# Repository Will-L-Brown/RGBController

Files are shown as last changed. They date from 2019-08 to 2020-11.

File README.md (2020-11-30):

# RGBController
Controller for RGB Strips and RGB Fans

Based on an Arduino Pro Micro (cheap chinese clone) 

Uses the FastLED library

Pin assignments can be found in the code

Recommended to have a resistor on the data output pins to the LED strips and fans, between 220Ω and 470Ω. I use 330Ω.

# 10-channel RGB Controller Hardware

This board is a custom board designed for hooking up to 10 aRGB devices with individual control using an Arduino Pro Micro. 

The Board features 9 3-pin aRGB headers and 1 Corsair RGB header. Idea is to have up to 8 RGB fans that are each individually addressable but do not pass the line back to have a combined effect, 
while also having a chain of Corsair RGB products and an aRGB strip.

There is a 3-button header for up to 3 standard case buttons, such as the unused reset switch!

This board is in a standard 2.5 inch drive format with mounting holes for easy case mounting.

# Known Hardware issues

- Rev 0.1A 
	- Incorrect pinout on the Corsair header
	
- Rev 0.1B
	- Corsair header does not have the best routing on VCC and GND to local filter capacitors
		- SMD stencil is compatible with Rev 0.1A hardware
	- BOM P/N for aRGB headers is incorrect. Correct part should be a 2.54mm spaced, 0.6mm diameter, right angle "Swiss machine pin" header to be compatible with standard aRGB connectors
		- I don't know of a good part number or source for this part. Contact me if you have a part number, or submit a pull request
	- BOM P/N for Molex power connect is likely not optimal. 
	- Spacing for aRGB headers may not be optimal for certain devices and may have clearance issues when completely populated
	- 0.1uF caps C12-16, C27-31 should not be populated. These destroy the signal from the ATMega and were intended for 5V-GND, not Din-GND

# Future Hardware To-Do

- Rev 0.1C
	- Re-routing filter caps for the Corsair header for better performace
- Future Variants
	- Change one aRGB header to a second Corsair header
	- Variant with 3 aRGB, 2 Cosair on one side, temp probes and fan headers on the other

# Off-The-Shelf components and LED Type
This is meant to use a variety of standard PC components as well as cheap RGB strips to produce the RGB effect.

A small list of various verified parts and their LED type are listed below:

- Corsair HD1x0 fans
    - WS2812B-based custom RGB modules
	- HD120: 12 LEDS
- Corsair XD5 Pump and Res Combo
    - WS2812B-based custom RGB modules
	- 10 LEDS
- Corsair XG7 RTX 2080 GPU Block
	- WS2812B-based custom RGB modules
	- 16 LEDS

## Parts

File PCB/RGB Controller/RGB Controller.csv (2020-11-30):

Source: | H:\Projects\8-ch RGB Controller\PCB\RGB Controller\RGB Controller.sch
Date: | 11/16/2020 6:00:43 PM
Tool: | Eeschema (5.1.7)-1
Generator: | C:\Program Files\KiCad\bin\scripting\plugins/bom_csv_grouped_by_value.py
Component Count: | 58
Individual Components:
Item | Qty | Reference(s) | Value | LibPart | Footprint | Datasheet | Digi-Key_PN | Field4 | MPN
 |  | B1 | SPARKFUN_PRO_MICRO | SparkFun-Boards:SPARKFUN_PRO_MICRO | Boards:SPARKFUN_PRO_MICRO |  |  | XXX-00000 | Pro Micro
 |  | C1 | 10uF | Device:C_Small | Capacitor_SMD:C_0603_1608Metric_Pad1.08x0.95mm_HandSolder | ~ | 1276-1119-1-ND |  | CL10A106MQ8NNNC
 |  | C2 | 10uF | Device:C_Small | Capacitor_SMD:C_0603_1608Metric_Pad1.08x0.95mm_HandSolder | ~ | 1276-1119-1-ND |  | CL10A106MQ8NNNC
 |  | C3 | 10uF | Device:C_Small | Capacitor_SMD:C_0603_1608Metric_Pad1.08x0.95mm_HandSolder | ~ | 1276-1119-1-ND |  | CL10A106MQ8NNNC
 |  | C4 | 10uF | Device:C_Small | Capacitor_SMD:C_0603_1608Metric_Pad1.08x0.95mm_HandSolder | ~ | 1276-1119-1-ND |  | CL10A106MQ8NNNC
 |  | C5 | 10uF | Device:C_Small | Capacitor_SMD:C_0603_1608Metric_Pad1.08x0.95mm_HandSolder | ~ | 1276-1119-1-ND |  | CL10A106MQ8NNNC
 |  | C6 | 10uF | Device:C_Small | Capacitor_SMD:C_0603_1608Metric_Pad1.08x0.95mm_HandSolder | ~ | 1276-1119-1-ND |  | CL10A106MQ8NNNC
 |  | C7 | 100uF | Device:CP1_Small | Custom Footprints:UWR1A101MCL1GB | ~ | 493-14561-1-ND |  | UWR1A101MCL1GB
 |  | C8 | 100uF | Device:CP1_Small | Custom Footprints:UWR1A101MCL1GB | ~ | 493-14561-1-ND |  | UWR1A101MCL1GB
 |  | C9 | 100uF | Device:CP1_Small | Custom Footprints:UWR1A101MCL1GB | ~ | 493-14561-1-ND |  | UWR1A101MCL1GB
 |  | C10 | 100uF | Device:CP1_Small | Custom Footprints:UWR1A101MCL1GB | ~ | 493-14561-1-ND |  | UWR1A101MCL1GB
 |  | C11 | 100uF | Device:CP1_Small | Custom Footprints:UWR1A101MCL1GB | ~ | 493-14561-1-ND |  | UWR1A101MCL1GB
 |  | C12 | 0.1uF | Device:C_Small | Capacitor_SMD:C_0402_1005Metric_Pad0.74x0.62mm_HandSolder | ~ | 490-3261-1-ND |  | GRM155R71C104KA88D
 |  | C13 | 0.1uF | Device:C_Small | Capacitor_SMD:C_0402_1005Metric_Pad0.74x0.62mm_HandSolder | ~ | 490-3261-1-ND |  | GRM155R71C104KA88D
 |  | C14 | 0.1uF | Device:C_Small | Capacitor_SMD:C_0402_1005Metric_Pad0.74x0.62mm_HandSolder | ~ | 490-3261-1-ND |  | GRM155R71C104KA88D
 |  | C15 | 0.1uF | Device:C_Small | Capacitor_SMD:C_0402_1005Metric_Pad0.74x0.62mm_HandSolder | ~ | 490-3261-1-ND |  | GRM155R71C104KA88D
 |  | C16 | 0.1uF | Device:C_Small | Capacitor_SMD:C_0402_1005Metric_Pad0.74x0.62mm_HandSolder | ~ | 490-3261-1-ND |  | GRM155R71C104KA88D
 |  | C17 | 10uF | Device:C_Small | Capacitor_SMD:C_0603_1608Metric_Pad1.08x0.95mm_HandSolder | ~ | 1276-1119-1-ND |  | CL10A106MQ8NNNC
 |  | C18 | 10uF | Device:C_Small | Capacitor_SMD:C_0603_1608Metric_Pad1.08x0.95mm_HandSolder | ~ | 1276-1119-1-ND |  | CL10A106MQ8NNNC
 |  | C19 | 10uF | Device:C_Small | Capacitor_SMD:C_0603_1608Metric_Pad1.08x0.95mm_HandSolder | ~ | 1276-1119-1-ND |  | CL10A106MQ8NNNC
 |  | C20 | 10uF | Device:C_Small | Capacitor_SMD:C_0603_1608Metric_Pad1.08x0.95mm_HandSolder | ~ | 1276-1119-1-ND |  | CL10A106MQ8NNNC
 |  | C21 | 10uF | Device:C_Small | Capacitor_SMD:C_0603_1608Metric_Pad1.08x0.95mm_HandSolder | ~ | 1276-1119-1-ND |  | CL10A106MQ8NNNC
 |  | C22 | 100uF | Device:CP1_Small | Custom Footprints:UWR1A101MCL1GB | ~ | 493-14561-1-ND |  | UWR1A101MCL1GB
 |  | C23 | 100uF | Device:CP1_Small | Custom Footprints:UWR1A101MCL1GB | ~ | 493-14561-1-ND |  | UWR1A101MCL1GB
 |  | C24 | 100uF | Device:CP1_Small | Custom Footprints:UWR1A101MCL1GB | ~ | 493-14561-1-ND |  | UWR1A101MCL1GB
 |  | C25 | 100uF | Device:CP1_Small | Custom Footprints:UWR1A101MCL1GB | ~ | 493-14561-1-ND |  | UWR1A101MCL1GB
 |  | C26 | 100uF | Device:CP1_Small | Custom Footprints:UWR1A101MCL1GB | ~ | 493-14561-1-ND |  | UWR1A101MCL1GB
 |  | C27 | 0.1uF | Device:C_Small | Capacitor_SMD:C_0402_1005Metric_Pad0.74x0.62mm_HandSolder | ~ | 490-3261-1-ND |  | GRM155R71C104KA88D
 |  | C28 | 0.1uF | Device:C_Small | Capacitor_SMD:C_0402_1005Metric_Pad0.74x0.62mm_HandSolder | ~ | 490-3261-1-ND |  | GRM155R71C104KA88D
 |  | C29 | 0.1uF | Device:C_Small | Capacitor_SMD:C_0402_1005Metric_Pad0.74x0.62mm_HandSolder | ~ | 490-3261-1-ND |  | GRM155R71C104KA88D
 |  | C30 | 0.1uF | Device:C_Small | Capacitor_SMD:C_0402_1005Metric_Pad0.74x0.62mm_HandSolder | ~ | 490-3261-1-ND |  | GRM155R71C104KA88D
 |  | C31 | 0.1uF | Device:C_Small | Capacitor_SMD:C_0402_1005Metric_Pad0.74x0.62mm_HandSolder | ~ | 490-3261-1-ND |  | GRM155R71C104KA88D
 |  | C32 | 100uF | Device:CP1_Small | Custom Footprints:UWR1A101MCL1GB | ~ | 493-14561-1-ND |  | UWR1A101MCL1GB
 |  | J1 | Conn_01x06 | Connector_Generic:Conn_01x06 | Connector_PinHeader_2.54mm:PinHeader_1x06_P2.54mm_Horizontal | ~
 |  | J2 | Conn_01x04 | Connector_Generic:Conn_01x04 | Connector_PinHeader_2.54mm:PinHeader_1x04_P2.54mm_Horizontal | ~ | 1212-1309-ND |  | 830-10-004-20-001101
 |  | J3 | Conn_01x04 | Connector_Generic:Conn_01x04 | Connector_PinHeader_2.54mm:PinHeader_1x04_P2.54mm_Horizontal | ~ | 1212-1309-ND |  | 830-10-004-20-001101
 |  | J4 | Conn_01x04 | Connector_Generic:Conn_01x04 | Connector_PinHeader_2.54mm:PinHeader_1x04_P2.54mm_Horizontal | ~ | 1212-1309-ND |  | 830-10-004-20-001101
 |  | J5 | Conn_01x04 | Connector_Generic:Conn_01x04 | Connector_PinHeader_2.54mm:PinHeader_1x04_P2.54mm_Horizontal | ~ | 1212-1309-ND |  | 830-10-004-20-001101
 |  | J6 | Conn_01x04 | Connector_Generic:Conn_01x04 | Connector_PinHeader_2.54mm:PinHeader_1x04_P2.54mm_Horizontal | ~ | 1212-1309-ND |  | 830-10-004-20-001101
 |  | J7 | Conn_01x04 | Connector_Generic:Conn_01x04 | Connector_PinHeader_2.54mm:PinHeader_1x04_P2.54mm_Horizontal | ~ | 1212-1309-ND |  | 830-10-004-20-001101
 |  | J8 | Conn_01x04 | Connector_Generic:Conn_01x04 | Connector_PinHeader_2.54mm:PinHeader_1x04_P2.54mm_Horizontal | ~ | 1212-1309-ND |  | 830-10-004-20-001101
 |  | J9 | Conn_01x04 | Connector_Generic:Conn_01x04 | Connector_PinHeader_2.54mm:PinHeader_1x04_P2.54mm_Horizontal | ~ | 1212-1309-ND |  | 830-10-004-20-001101
 |  | J10 | Conn_01x04 | Connector_Generic:Conn_01x04 | Connector_PinHeader_2.54mm:PinHeader_1x04_P2.54mm_Horizontal | ~ | 1212-1309-ND |  | 830-10-004-20-001101
 |  | J11 | Conn_01x03 | Connector_Generic:Conn_01x03 | Custom Footprints:70555-0002 | ~ | WM4176-ND |  | 70555-0002
 |  | J12 | 641737-1 | 2020-11-15_23-26-44:827001-2 | Custom Footprints:827001-2 |  | A25430-ND |  | 641737-1
 |  | R1 | 330 | Device:R_Small_US | Resistor_SMD:R_0402_1005Metric_Pad0.72x0.64mm_HandSolder | ~ | A129621CT-ND |  | CRGCQ0402F330R
 |  | R2 | 330 | Device:R_Small_US | Resistor_SMD:R_0402_1005Metric_Pad0.72x0.64mm_HandSolder | ~ | A129621CT-ND |  | CRGCQ0402F330R
 |  | R3 | 330 | Device:R_Small_US | Resistor_SMD:R_0402_1005Metric_Pad0.72x0.64mm_HandSolder | ~ | A129621CT-ND |  | CRGCQ0402F330R
 |  | R4 | 330 | Device:R_Small_US | Resistor_SMD:R_0402_1005Metric_Pad0.72x0.64mm_HandSolder | ~ | A129621CT-ND |  | CRGCQ0402F330R
 |  | R5 | 330 | Device:R_Small_US | Resistor_SMD:R_0402_1005Metric_Pad0.72x0.64mm_HandSolder | ~ | A129621CT-ND |  | CRGCQ0402F330R
 |  | R6 | 330 | Device:R_Small_US | Resistor_SMD:R_0402_1005Metric_Pad0.72x0.64mm_HandSolder | ~ | A129621CT-ND |  | CRGCQ0402F330R
 |  | R7 | 330 | Device:R_Small_US | Resistor_SMD:R_0402_1005Metric_Pad0.72x0.64mm_HandSolder | ~ | A129621CT-ND |  | CRGCQ0402F330R
 |  | R8 | 330 | Device:R_Small_US | Resistor_SMD:R_0402_1005Metric_Pad0.72x0.64mm_HandSolder | ~ | A129621CT-ND |  | CRGCQ0402F330R
 |  | R9 | 330 | Device:R_Small_US | Resistor_SMD:R_0402_1005Metric_Pad0.72x0.64mm_HandSolder | ~ | A129621CT-ND |  | CRGCQ0402F330R
 |  | R10 | 330 | Device:R_Small_US | Resistor_SMD:R_0402_1005Metric_Pad0.72x0.64mm_HandSolder | ~ | A129621CT-ND |  | CRGCQ0402F330R
 |  | R11 | 10k | Device:R_Small_US | Resistor_SMD:R_0402_1005Metric_Pad0.72x0.64mm_HandSolder | ~ | P10.0KLCT-ND |  | ERJ-2RKF1002X
 |  | R12 | 10k | Device:R_Small_US | Resistor_SMD:R_0402_1005Metric_Pad0.72x0.64mm_HandSolder | ~ | P10.0KLCT-ND |  | ERJ-2RKF1002X
 |  | R13 | 10k | Device:R_Small_US | Resistor_SMD:R_0402_1005Metric_Pad0.72x0.64mm_HandSolder | ~ | P10.0KLCT-ND |  | ERJ-2RKF1002X
Collated Components:
Item | Qty | Reference(s) | Value | LibPart | Footprint | Datasheet | Digi-Key_PN | Field4 | MPN
1 | 1 | B1 | SPARKFUN_PRO_MICRO | SparkFun-Boards:SPARKFUN_PRO_MICRO | Boards:SPARKFUN_PRO_MICRO |  |  | XXX-00000 | Pro Micro
2 | 11 | C1, C2, C3, C4, C5, C6, C17, C18, C19, C20, C21 | 10uF | Device:C_Small | Capacitor_SMD:C_0603_1608Metric_Pad1.08x0.95mm_HandSolder | ~ | 1276-1119-1-ND |  | CL10A106MQ8NNNC
3 | 11 | C7, C8, C9, C10, C11, C22, C23, C24, C25, C26, C32 | 100uF | Device:CP1_Small | Custom Footprints:UWR1A101MCL1GB | ~ | 493-14561-1-ND |  | UWR1A101MCL1GB
4 | 10 | C12, C13, C14, C15, C16, C27, C28, C29, C30, C31 | 0.1uF | Device:C_Small | Capacitor_SMD:C_0402_1005Metric_Pad0.74x0.62mm_HandSolder | ~ | 490-3261-1-ND |  | GRM155R71C104KA88D
5 | 1 | J1 | Conn_01x06 | Connector_Generic:Conn_01x06 | Connector_PinHeader_2.54mm:PinHeader_1x06_P2.54mm_Horizontal | ~
6 | 9 | J2, J3, J4, J5, J6, J7, J8, J9, J10 | Conn_01x04 | Connector_Generic:Conn_01x04 | Connector_PinHeader_2.54mm:PinHeader_1x04_P2.54mm_Horizontal | ~ | 1212-1309-ND |  | 830-10-004-20-001101
7 | 1 | J11 | Conn_01x03 | Connector_Generic:Conn_01x03 | Custom Footprints:70555-0002 | ~ | WM4176-ND |  | 70555-0002
8 | 1 | J12 | 641737-1 | 2020-11-15_23-26-44:827001-2 | Custom Footprints:827001-2 |  | A25430-ND |  | 641737-1
9 | 10 | R1, R2, R3, R4, R5, R6, R7, R8, R9, R10 | 330 | Device:R_Small_US | Resistor_SMD:R_0402_1005Metric_Pad0.72x0.64mm_HandSolder | ~ | A129621CT-ND |  | CRGCQ0402F330R
10 | 3 | R11, R12, R13 | 10k | Device:R_Small_US | Resistor_SMD:R_0402_1005Metric_Pad0.72x0.64mm_HandSolder | ~ | P10.0KLCT-ND |  | ERJ-2RKF1002X

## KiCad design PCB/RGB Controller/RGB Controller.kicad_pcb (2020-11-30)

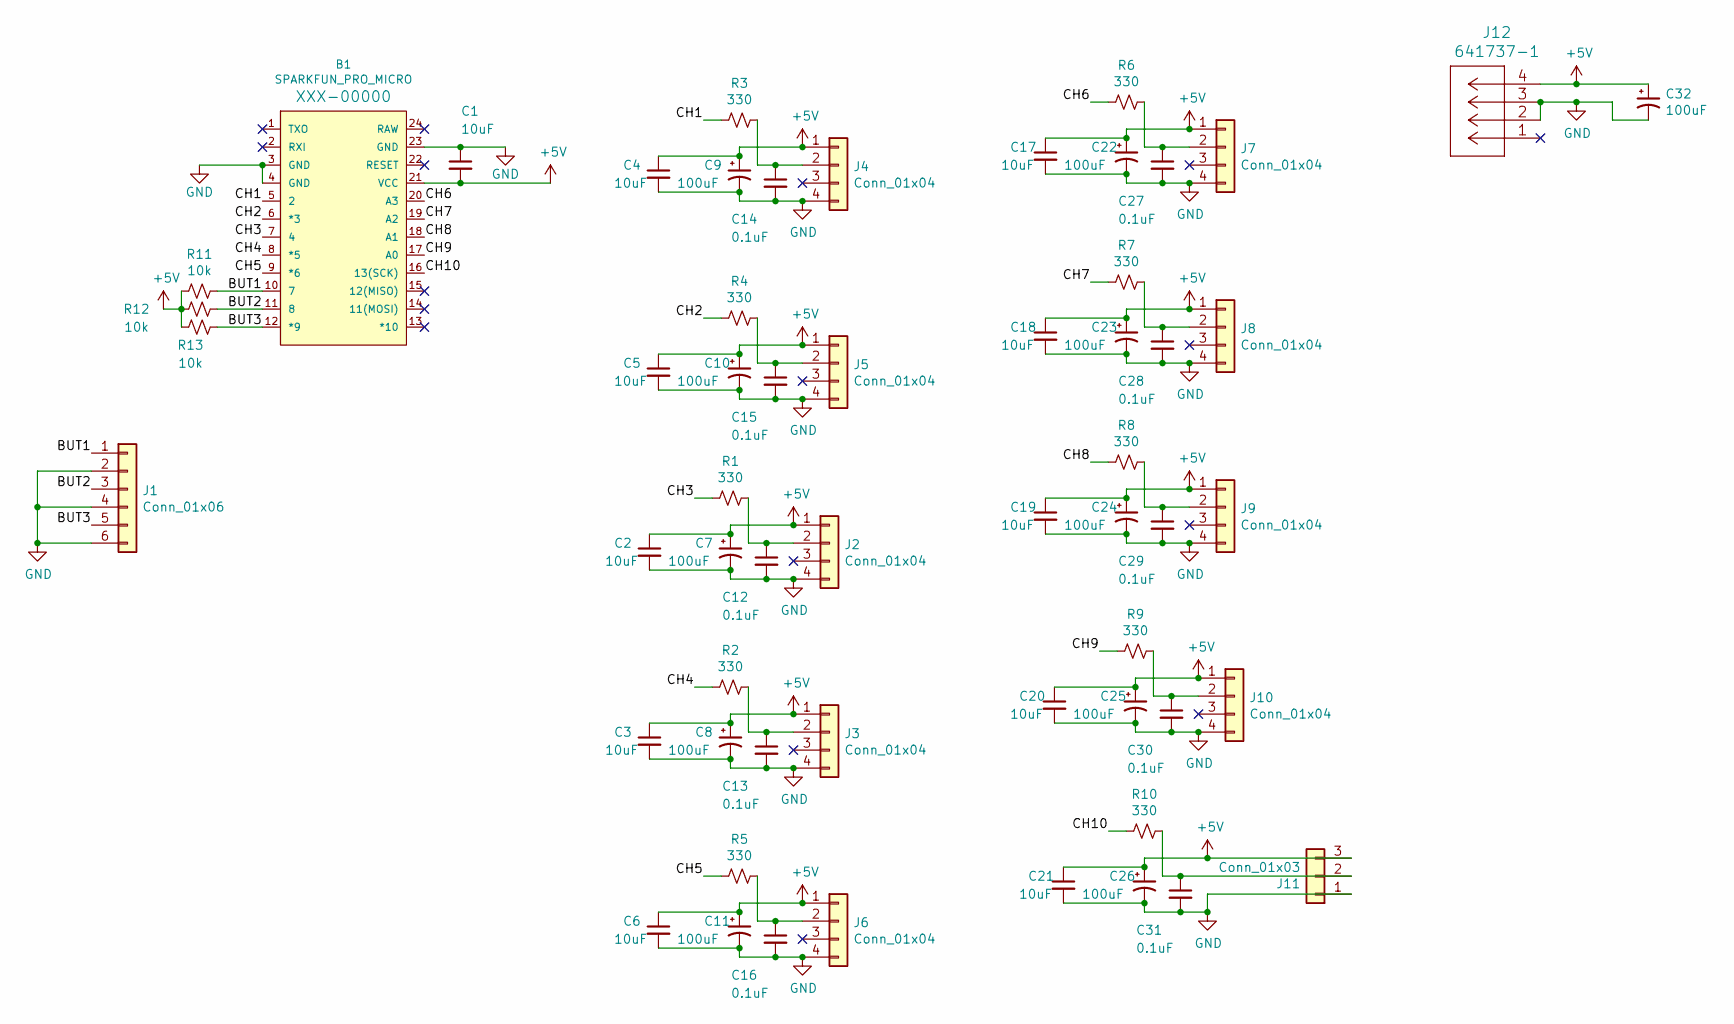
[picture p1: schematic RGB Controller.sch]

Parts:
B1: SPARKFUN_PRO_MICRO; MPN Pro Micro
C1, C2, C3, C4, C5, C6, C17, C18, C19, C20, C21: 10uF; C_0603_1608Metric_Pad1.08x0.95mm_HandSolder; MPN CL10A106MQ8NNNC; Digi-Key_PN 1276-1119-1-ND
C7, C8, C9, C10, C11, C22, C23, C24, C25, C26, C32: 100uF; UWR1A101MCL1GB; MPN UWR1A101MCL1GB; Digi-Key_PN 493-14561-1-ND
C12, C13, C14, C15, C16, C27, C28, C29, C30, C31: 0.1uF; C_0402_1005Metric_Pad0.74x0.62mm_HandSolder; MPN GRM155R71C104KA88D; Digi-Key_PN 490-3261-1-ND
J1: Conn_01x06; PinHeader_1x06_P2.54mm_Horizontal
J2, J3, J4, J5, J6, J7, J8, J9, J10: Conn_01x04; PinHeader_1x04_P2.54mm_Horizontal; MPN 830-10-004-20-001101; Digi-Key_PN 1212-1309-ND
J11: Conn_01x03; 70555-0002; MPN 70555-0002; Digi-Key_PN WM4176-ND
J12: 641737-1; 827001-2; MPN 641737-1; Digi-Key_PN A25430-ND
R1, R2, R3, R4, R5, R6, R7, R8, R9, R10: 330; R_0402_1005Metric_Pad0.72x0.64mm_HandSolder; MPN CRGCQ0402F330R; Digi-Key_PN A129621CT-ND
R11, R12, R13: 10k; R_0402_1005Metric_Pad0.72x0.64mm_HandSolder; MPN ERJ-2RKF1002X; Digi-Key_PN P10.0KLCT-ND

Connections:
+5V: B1.21 (VCC), C1.2, C2.1, C3.1, C4.1, C5.1, C6.1, C7.1, C8.1, C9.1, C10.1, C11.1, C17.1, C18.1, C19.1, C20.1, C21.1, C22.1, C23.1, C24.1, C25.1, C26.1, C32.1, J2.1, J3.1, J4.1, J5.1, J6.1, J7.1, J8.1, J9.1, J10.1, J11.3, J12.4, R11.2, R12.2, R13.2
/BUT1: B1.10 (7), J1.1, R11.1
/BUT2: B1.11 (8), J1.3, R12.1
/BUT3: B1.12 (*9), J1.5, R13.1
/CH1: B1.5 (2), R3.2
/CH2: B1.6 (*3), R4.2
/CH3: B1.7 (4), R1.2
/CH4: B1.8 (*5), R2.2
/CH5: B1.9 (*6), R5.2
/CH6: B1.20 (A3), R6.2
/CH7: B1.19 (A2), R7.2
/CH8: B1.18 (A1), R8.2
/CH9: B1.17 (A0), R9.2
/CH10: B1.16 (13(SCK)), R10.2
GND: B1.3 (GND), B1.4 (GND), B1.23 (GND), C1.1, C2.2, C3.2, C4.2, C5.2, C6.2, C7.2, C8.2, C9.2, C10.2, C11.2, C12.2, C13.2, C14.2, C15.2, C16.2, C17.2, C18.2, C19.2, C20.2, C21.2, C22.2, C23.2, C24.2, C25.2, C26.2, C27.2, C28.2, C29.2, C30.2, C31.2, C32.2, J1.2, J1.4, J1.6, J2.4, J3.4, J4.4, J5.4, J6.4, J7.4, J8.4, J9.4, J10.4, J11.1, J12.2, J12.3
unnamed: C12.1, J2.2, R1.1
unnamed: C13.1, J3.2, R2.1
unnamed: C14.1, J4.2, R3.1
unnamed: C15.1, J5.2, R4.1
unnamed: C16.1, J6.2, R5.1
unnamed: C27.1, J7.2, R6.1
unnamed: C28.1, J8.2, R7.1
unnamed: C29.1, J9.2, R8.1
unnamed: C30.1, J10.2, R9.1
unnamed: C31.1, J11.2, R10.1

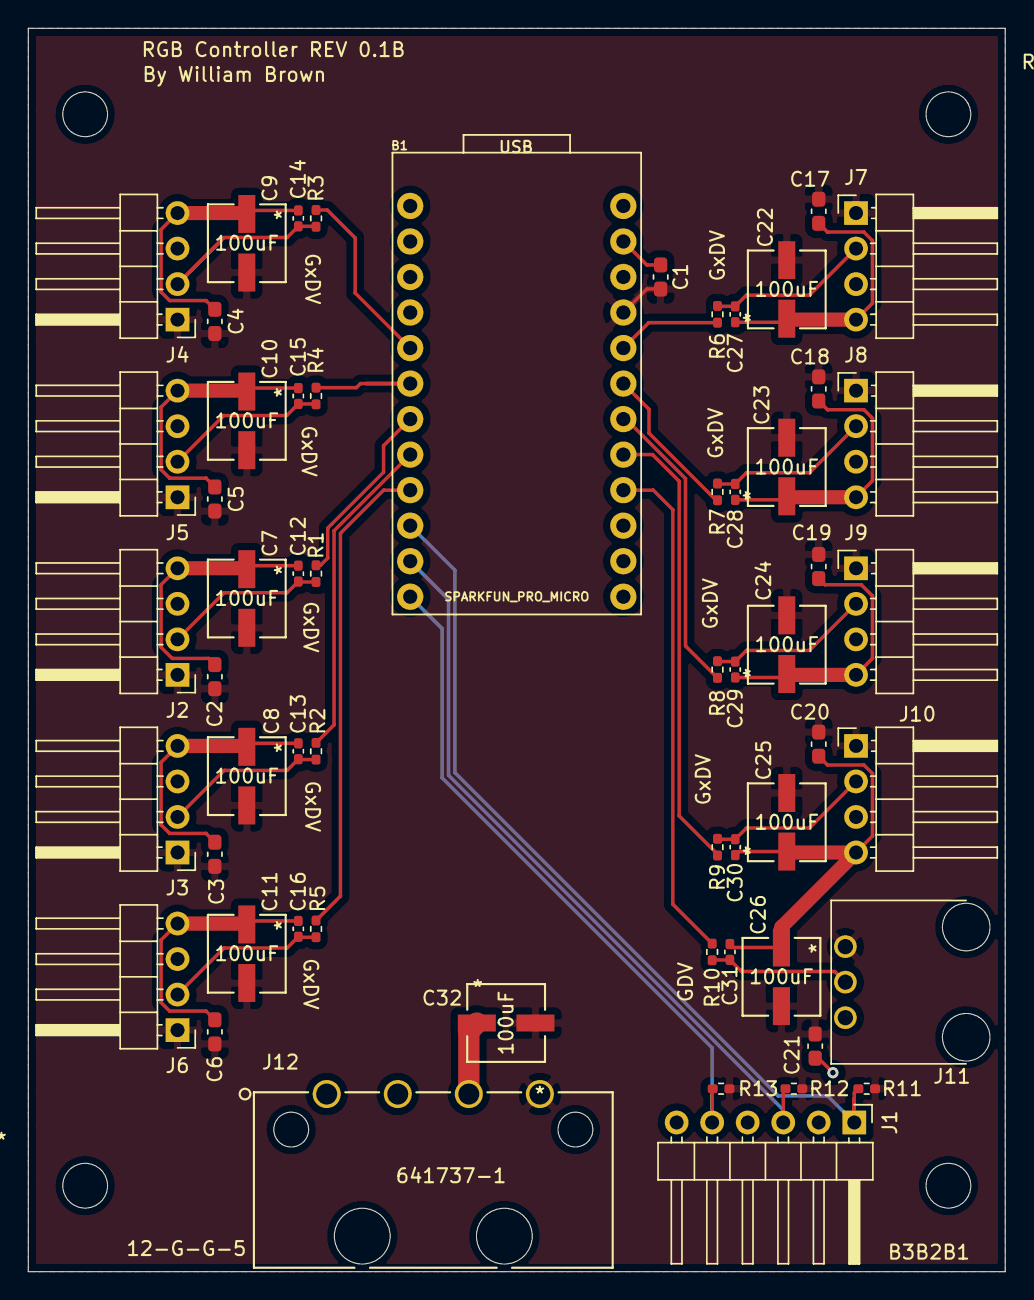
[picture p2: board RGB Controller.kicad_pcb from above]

Board: 2 copper layers, 69.9 x 88.9 mm, 58 parts (0 on the bottom side), 25 nets.

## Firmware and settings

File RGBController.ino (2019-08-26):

#include "FastLED.h"

FASTLED_USING_NAMESPACE

/* RGB Controller for PCs
 *  Developed at some point from some example code
 *  Don't really know what this does but hey it works
 *  
 *  Be careful
 *  
 *  William
 *  Aug 2019
 */

#if defined(FASTLED_VERSION) && (FASTLED_VERSION < 3001000)
#warning "Requires FastLED 3.1 or later; check github for latest code."
#endif



/* In my install, LED1 is my pump and fans, LED2 is my RGB strip
 *  Keep that in mind going through the code
 */
#define DATA_PIN    5
#define DATA_PIN_2  10

#define LED_TYPE    WS2812
#define LED_TYPE_2    WS2812

#define COLOR_ORDER GRB

#define NUM_LEDS    98 
#define NUM_LEDS2    76

CRGB leds[NUM_LEDS];
CRGB leds2[NUM_LEDS2];

#define BRIGHTNESS          50
#define MIN_BRIGHTNESS      26

// Tied to the input for the case buttons
#define PATTERN_BUTTON 3
#define SPEED_BUTTON 4
#define COLOR_BUTTON 2

#define ARRAY_SIZE(A) (sizeof(A) / sizeof((A)[0]))


int fps = 240;

CLEDController *controllers[2];

int colorCount = 0;

uint8_t gCurrentPatternNumber = 0; // Index number of which pattern is current
uint8_t gHue = 0; // rotating "base color" used by many of the patterns

bool advPat = false; // For button cycle of modes
bool advSpd = false; // For button cycle of modes
bool advClr = false; // For button cycle of modes

bool cycleHue = true;

void setup() {
  
  // tell FastLED about the LED strip configuration
  FastLED.addLeds<LED_TYPE,DATA_PIN,COLOR_ORDER>(leds, NUM_LEDS);
  FastLED.addLeds<LED_TYPE_2,DATA_PIN_2,COLOR_ORDER>(leds2, NUM_LEDS2);

  // Configure button input
  pinMode(PATTERN_BUTTON, INPUT);
  pinMode(SPEED_BUTTON, INPUT);
  pinMode(COLOR_BUTTON, INPUT);
}

// List of patterns to cycle through.  Each is defined as a separate function below.
// Defined here because fuck you?
typedef void (*SimplePatternList[])();
SimplePatternList gPatterns = { rainbow, rainbow2, breathing, sinelon, sinelon2, blank, sam , test };

void loop()
{
  // Call the current pattern function once, updating the 'leds' array
  gPatterns[gCurrentPatternNumber]();

  // send the 'leds' array out to the actual LED strip
  FastLED[0].showLeds(255);
  FastLED[1].showLeds(BRIGHTNESS);

  // do some periodic updates
  if (cycleHue || gCurrentPatternNumber == 5) {
    EVERY_N_MILLISECONDS( 20 ) { gHue++; } // slowly cycle the "base color" through the rainbow
  }

  if (digitalRead(PATTERN_BUTTON) && !advPat) {
    nextPattern();
    advPat = true;
  }
  else if (!digitalRead(PATTERN_BUTTON) && advPat) {
    advPat = false;
  }

  if (digitalRead(SPEED_BUTTON) && !advSpd) {
    nextSpeed();
    advSpd = true;
  }
  else if (!digitalRead(SPEED_BUTTON) && advSpd) {
    advSpd = false;
  }

  if (digitalRead(COLOR_BUTTON) && !advClr) {
    nextColor();
    advClr = true;
  }
  else if (!digitalRead(COLOR_BUTTON) && advClr) {
    advClr = false;
  }
}

void nextColor() {  
  colorCount++;
  
  if (colorCount > 9) colorCount = 0;
  
  if (colorCount == 0) {
    cycleHue = true;
  }
  else {
    cycleHue = false;
    gHue = (colorCount - 1) * 32;
  }
}

void nextPattern()
{
  // add one to the current pattern number, and wrap around at the end
  gCurrentPatternNumber = (gCurrentPatternNumber + 1) % ARRAY_SIZE( gPatterns);
}

// Not actually implemented.....
void nextSpeed()
{
  // add 20 FPS and wrap it around to 20
  fps = (fps % 240) + 20;
}

void blank() {
  for( int i = 0; i < NUM_LEDS; i++) { //9948
    leds[i] = CRGB::Black;
  }
  for( int i = 0; i < NUM_LEDS2; i++) { //9948
    leds2[i] = CRGB::Black;
  }
}

// In honor of a request from an old roommate, I give you "Sam"
// Please don't judge
void sam()
{
  for( int i = 0; i < NUM_LEDS; i++) { //9948
    leds[i].r = random(0, 255);
    leds[i].g = random(0, 255);
    leds[i].b = random(0, 255);
  }
  for( int i = 0; i < NUM_LEDS2; i++) { //9948
    leds2[i].r = random(0, 255);
    leds2[i].g = random(0, 255);
    leds2[i].b = random(0, 255);
  }

  delay(5);
}

void test()
{
  fill_rainbow( leds, NUM_LEDS, gHue, 100);
  fill_rainbow( leds2, NUM_LEDS2, gHue, 50);
}

// The following functions are pretty much copied from FastLED example code

void breathing() {
  float breath = (exp(sin(millis()/2000.0*PI)) - 0.36787944)*108.0;
  if (breath < MIN_BRIGHTNESS) breath = 0;
  fill_solid(leds, ARRAY_SIZE(leds), CHSV(gHue, 187, breath));
  fill_solid(leds2, ARRAY_SIZE(leds2), CHSV(gHue, 187, breath));
}

void rainbow() 
{
  // FastLED's built-in rainbow generator
  fill_rainbow( leds, NUM_LEDS, gHue, 0);
  fill_rainbow( leds2, NUM_LEDS2, gHue, 0);
}

void rainbow2() 
{
  // FastLED's built-in rainbow generator
  fill_rainbow( leds, NUM_LEDS, gHue, 5);
  fill_rainbow( leds2, NUM_LEDS2, gHue, 5);
}

void rainbowWithGlitter() 
{
  // built-in FastLED rainbow, plus some random sparkly glitter
  rainbow();
  addGlitter(80);
}

void addGlitter( fract8 chanceOfGlitter) 
{
  if( random8() < chanceOfGlitter) {
    leds[ random16(NUM_LEDS) ] += CRGB::White;
  }
  if( random8() < chanceOfGlitter) {
    leds2[ random16(NUM_LEDS2) ] += CRGB::White;
  }
}

void confetti() 
{
  // random colored speckles that blink in and fade smoothly
  fadeToBlackBy( leds, NUM_LEDS, 10);
  int pos = random16(NUM_LEDS);
  leds[pos] += CHSV( gHue + random8(64), 200, 255);
}

void sinelon()
{
  // a colored dot sweeping back and forth, with fading trails
  fadeToBlackBy( leds, NUM_LEDS, 4);
  int pos = beatsin16(13,0,NUM_LEDS - 1);
  if (pos < 16) pos = 16 - pos; // Flip GPU orientation
  leds[pos] += CHSV( gHue, 255, 192);
  
  fadeToBlackBy( leds2, NUM_LEDS2, 4);
  pos = beatsin16(13,0,NUM_LEDS2 - 1);
  pos = NUM_LEDS2 - pos - 1;
  leds2[pos] += CHSV( gHue, 255, 192);
}

void sinelon2()
{
  // a colored dot sweeping back and forth, with fading trails
  fadeToBlackBy( leds, NUM_LEDS, 4);
  int pos = beatsin16(13,0,NUM_LEDS - 1);
  if (pos < 16) pos = 16 - pos; // Flip GPU orientation
  leds[pos] += CHSV( gHue, 255, 192);
  pos = NUM_LEDS - pos - 1; 
  if (pos < 16) pos = 16 - pos; // Flip GPU orientation
  leds[pos] += CHSV( 255 - gHue, 255, 192);
  
  fadeToBlackBy( leds2, NUM_LEDS2, 4);
  pos = beatsin16(13,0,NUM_LEDS2 - 1);
  leds2[pos] += CHSV( gHue, 255, 192);
  pos = NUM_LEDS2 - pos - 1;
  leds2[pos] += CHSV( 255 - gHue, 255, 192);
}

void bpm()
{
  // colored stripes pulsing at a defined Beats-Per-Minute (BPM)
  uint8_t BeatsPerMinute = 62;
  CRGBPalette16 palette = PartyColors_p;
  uint8_t beat = beatsin8( BeatsPerMinute, 64, 255);
  for( int i = 0; i < NUM_LEDS; i++) { //9948
    leds[i] = ColorFromPalette(palette, gHue+(i*2), beat-gHue+(i*10));
  }
  for( int i = 0; i < NUM_LEDS2; i++) { //9948
    leds2[i] = ColorFromPalette(palette, gHue+(i*2), beat-gHue+(i*10));
  }
}

void juggle() {
  // eight colored dots, weaving in and out of sync with each other
  fadeToBlackBy( leds, NUM_LEDS, 20);
  byte dothue = 0;
  for( int i = 0; i < 8; i++) {
    leds[beatsin16(i+7,0,NUM_LEDS-1)] |= CHSV(dothue, 200, 255);
    dothue += 32;
  }

  fadeToBlackBy( leds2, NUM_LEDS2, 20);
  dothue = 0;
  for( int i = 0; i < 8; i++) {
    leds[beatsin16(i+7,0,NUM_LEDS2-1)] |= CHSV(dothue, 200, 255);
    dothue += 32;
  }
}

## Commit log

2020-11-30 Rev 0.1A hardware
    [RGB Controller-B_Cu.gbr, RGB Controller-B_Mask.gbr, RGB Controller-B_Paste.gbr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]
2020-11-30 Rev 0.1B hardware - Fixes Corsair Header pinout, 0.1A stencil compatible
    [RGB Controller.kicad_pcb, RGB Controller.sch]

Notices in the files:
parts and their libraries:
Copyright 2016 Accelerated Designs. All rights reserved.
